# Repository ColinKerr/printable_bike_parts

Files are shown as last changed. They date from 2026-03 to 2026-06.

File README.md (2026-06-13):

# Printable Bike Parts

A repo for bike parts you can 3d print

## Shimano 333 3-speed parts

Replacement parts for shimano 333 3 speed internal hub parts.

- [Top Cover](./shimano_333/TopCover.md) - Replaces often broken top cover.

## Clips

Various clips, tabs and screws used on bicycles.

- [Spoke Reflector Tab](./Clips/ReflectorSpokeTab.md) - Replaces tab used to hold reflectors on wheels via the spokes.
- [Spoke Reflector Screw](./Clips/ReflectorSpokeScrew.md) - Replaces screw used to hold reflectors on wheels via a spoke.

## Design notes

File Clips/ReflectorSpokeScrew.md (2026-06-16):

# Reflector Spoke Screw

Used on many modern bikes to hold wheel spoke reflectors onto a spoke.  The original part often breaks, or gets lost, this part is similar to the original but is modified to be printable without supports.

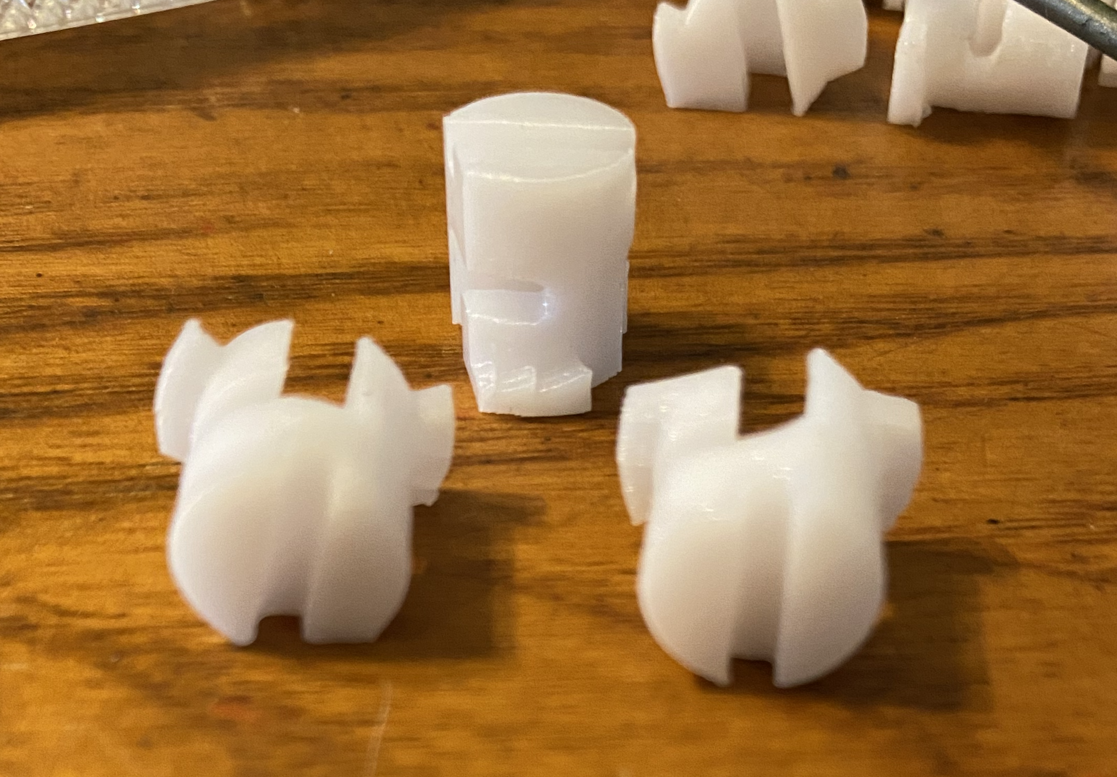
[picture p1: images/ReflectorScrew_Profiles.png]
Reflector Screw Profile


## Assembly instructions

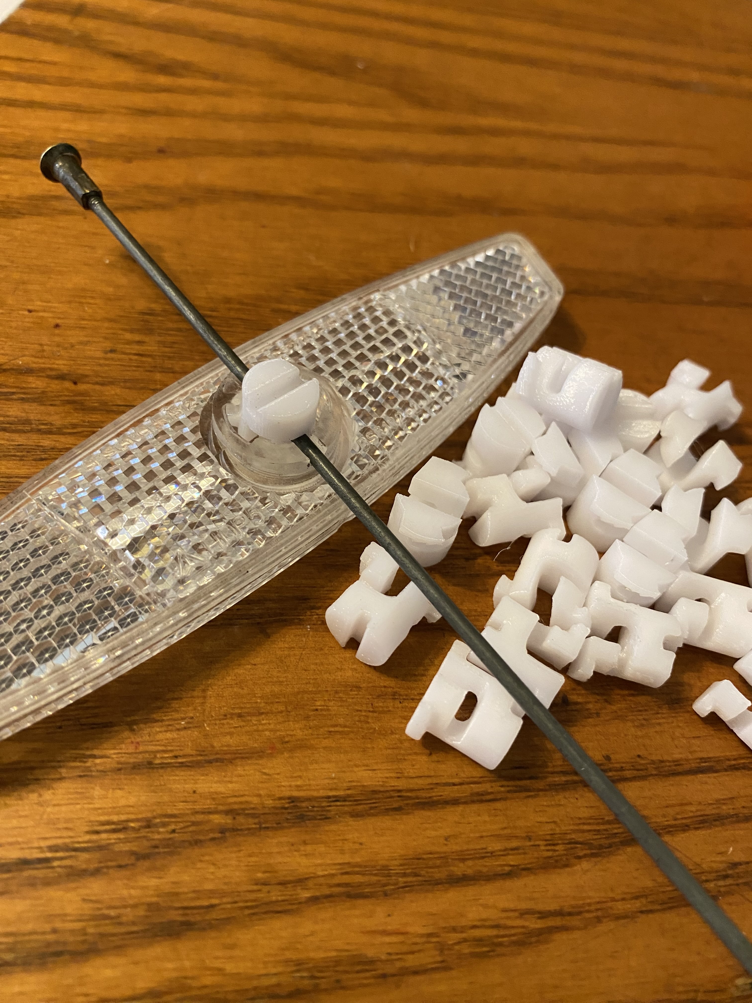
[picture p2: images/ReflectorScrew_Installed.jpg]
Reflector Screw Assembled


> Note: Make sure to press in with screw driver before turning

Use replacement screw as you would the original screw but be careful as PETG might be more flexible than original making part more prone to bend.

## Print settings

- PETG Suggested
  - PLA was to brittle for me but some other material stiffer than PETG would be ideal
- Print flat side down
- 100% infill
- 4 perimeters
- 0.1mm layer height
- No supports

> Warning: Bed adhesion is low, I suggest using smooth print bed or adhesion helper.

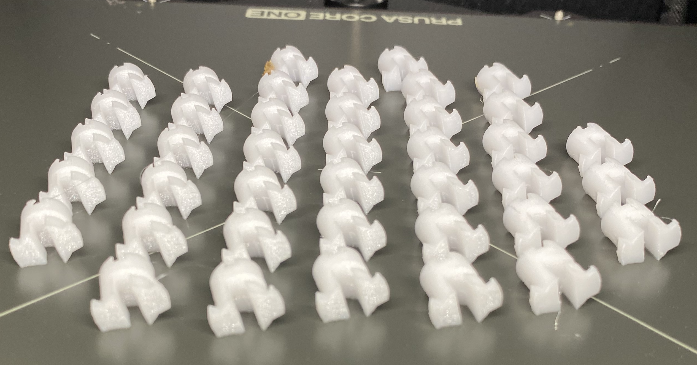
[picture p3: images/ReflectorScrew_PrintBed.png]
Reflector Screw On Print Bed


## ReflectorSpokeScrew.scad

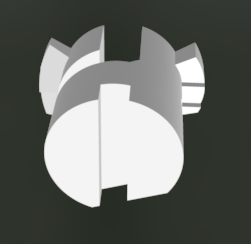
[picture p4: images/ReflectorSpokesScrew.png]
3d model of screw


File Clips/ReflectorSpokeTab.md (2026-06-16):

# Reflector Spoke Tab

Used on many older bikes to hold wheel spoke reflectors onto spokes.  The original part often breaks, this is a clone or the original part, best printed in PETG.

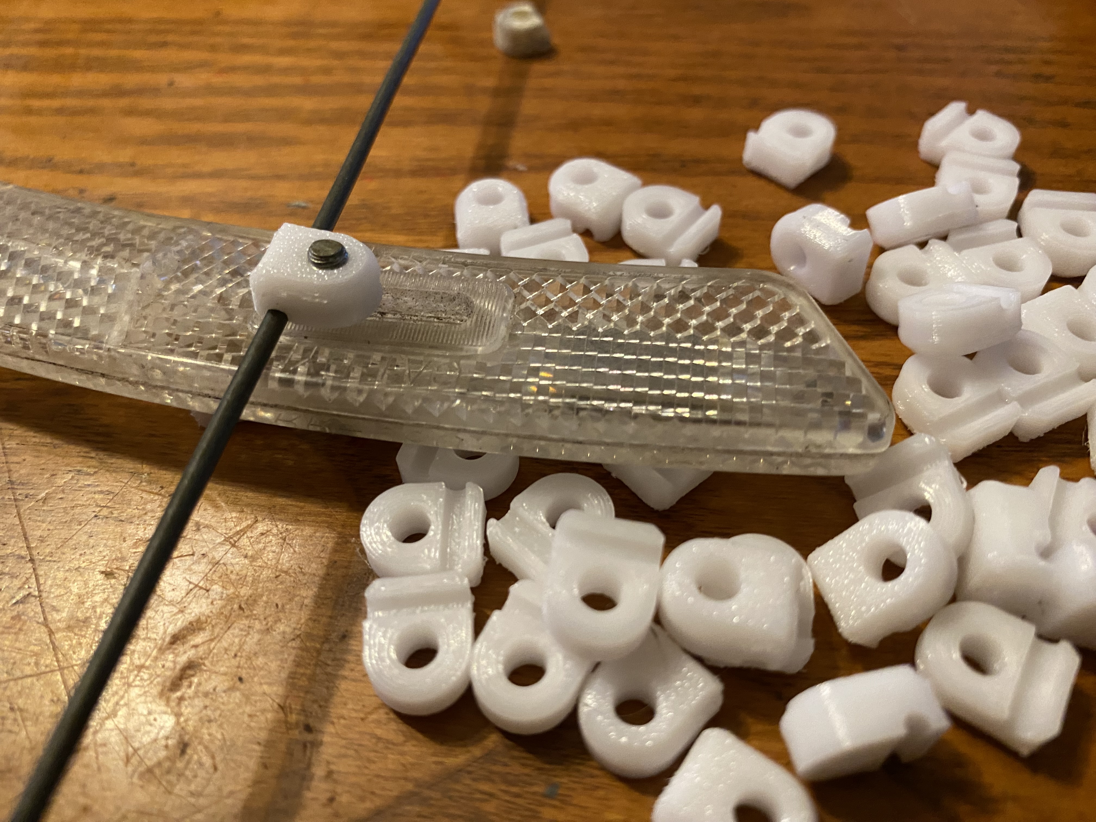
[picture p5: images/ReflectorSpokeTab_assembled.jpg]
Spoke Tabs


## Assembly instructions

> Note: Make sure grove in tab fits snugly around spoke be for assembly

Use replacement tab as you would the original tab but note that screw will thread into plastic on first use.

## Print settings

- PETG Suggested
- Print top side down
- 100% infill
- 4 perimeters
- 0.1mm layer height
- No Supports

## ReflectorSpokeTab.scad

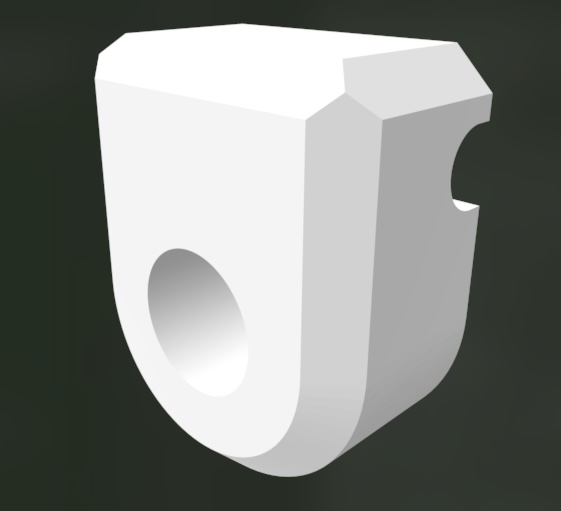
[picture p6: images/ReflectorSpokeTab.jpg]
3d model of tab


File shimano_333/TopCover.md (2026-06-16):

# Top Cover

The plastic top cover on the shifter is easily broken rendering the shifter non-functional.  The rest of the shifter generally remains functional, so a replacement top cover fixes the issue.

This part is designed to use either 4mm housing with a plastic cable end or a 5 mm housing with a metal end.  Reuse the screw, ball bearing and internal metal plate from the original shifter.

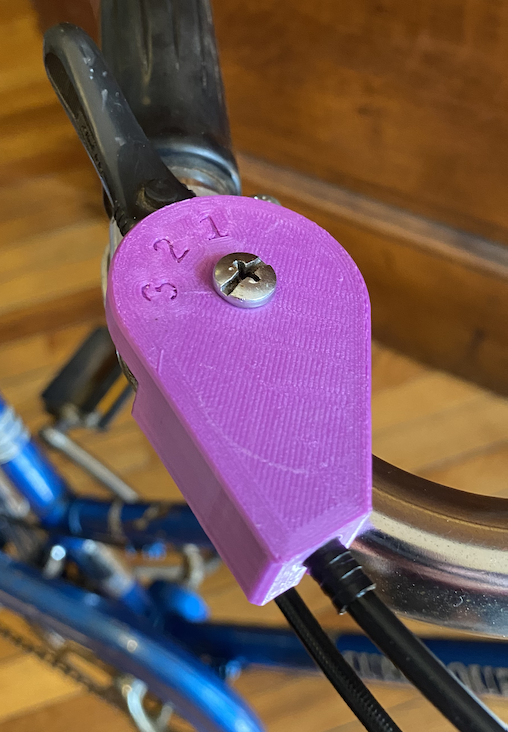
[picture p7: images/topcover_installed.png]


## Assembly instructions

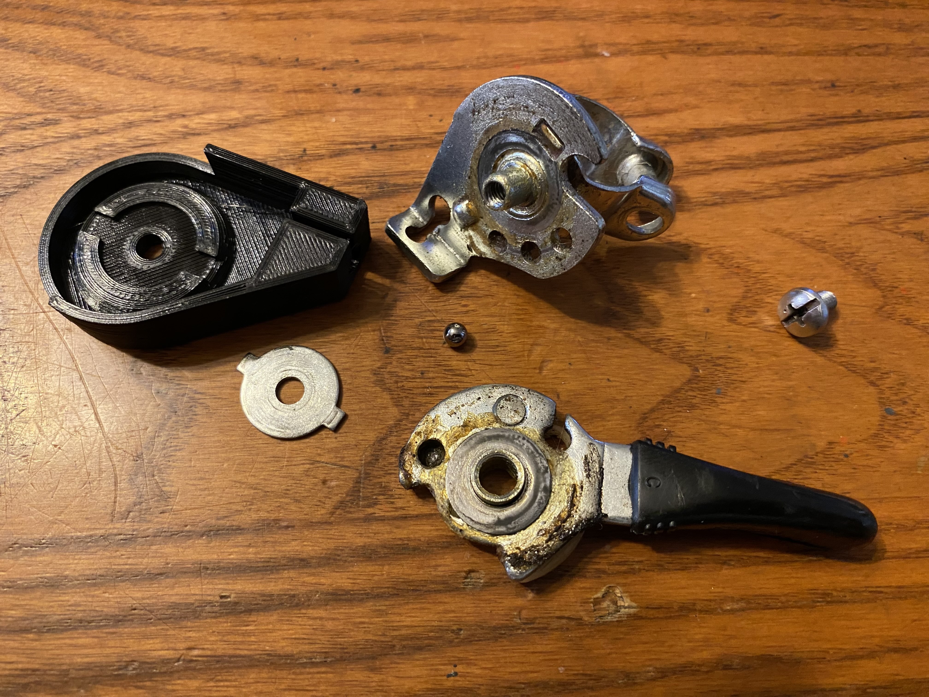
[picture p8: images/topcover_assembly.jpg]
shifter dissassembled


Dissassemble the broken shifter keeping mind of the order of parts.  Swap the broken housing for the 3d printed one and reassemble.  Mind the ball bearing, it may be loose or missing.

> Note 1: Some models of this shifter have tabs on the top metal washer some do not, both models work with the new top cover.
> Note 2: Ball bearing is 3/16"
> Note 3: Apply grease to the moving assemblies if dry

## Print settings

- PETG suggested
- Print top side down
- 100% infill
- 4-6 perimeters
- 0.1mm layer height
- (Optional) Fuzzzy skin on outside walls and chamfers to hide print lines

## TopCover.scad

This design has more plastic surrounding the cable housing area than the original for increased strength.

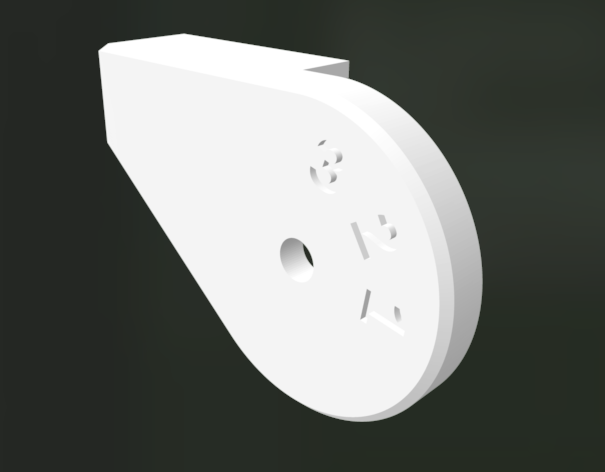
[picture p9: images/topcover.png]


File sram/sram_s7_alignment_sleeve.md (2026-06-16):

# SRAM S7 Alignment Sleeve

I didn't design this part so I will just link to post and describe how best to print it.  The part could be improved to have a longer tab so it is easier to remove from the click box but I did not attempt.

The STL can be found on [Thingiverse](https://www.thingiverse.com/thing:4240412)

## Print Settings

- PETG Suggested
- Print tab side down
- 100% infill
- 4 perimeters
- 0.1mm layer height
- Supports to Bed Only

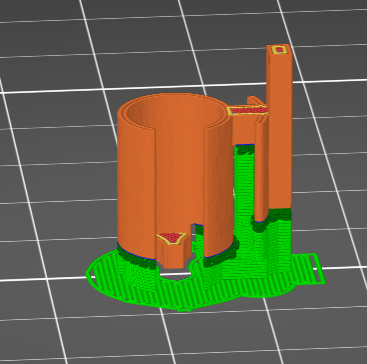
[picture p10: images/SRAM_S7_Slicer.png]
Sleeve in Slicer


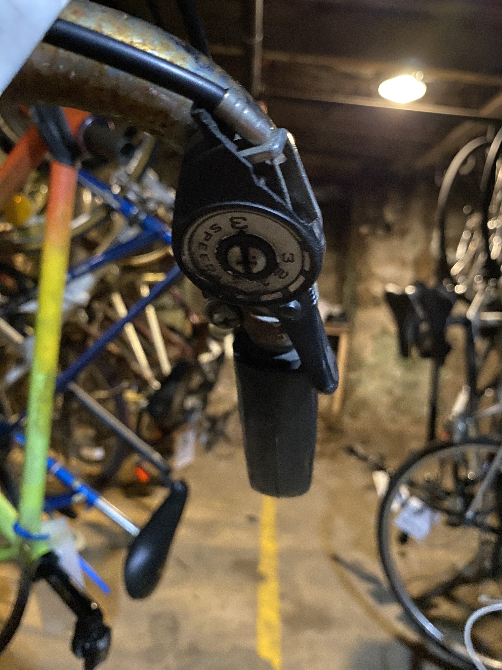
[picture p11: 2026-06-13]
images/topcover_broken.jpg

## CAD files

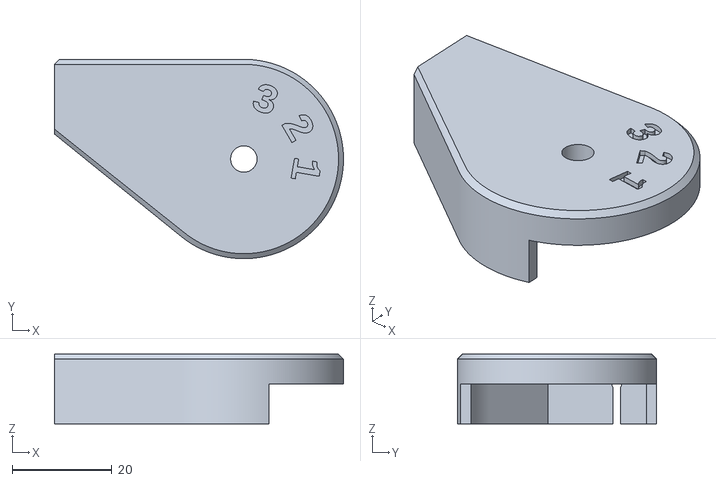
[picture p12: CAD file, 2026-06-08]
shimano_333/TopCover.stl
58.0 x 40.0 x 14.0

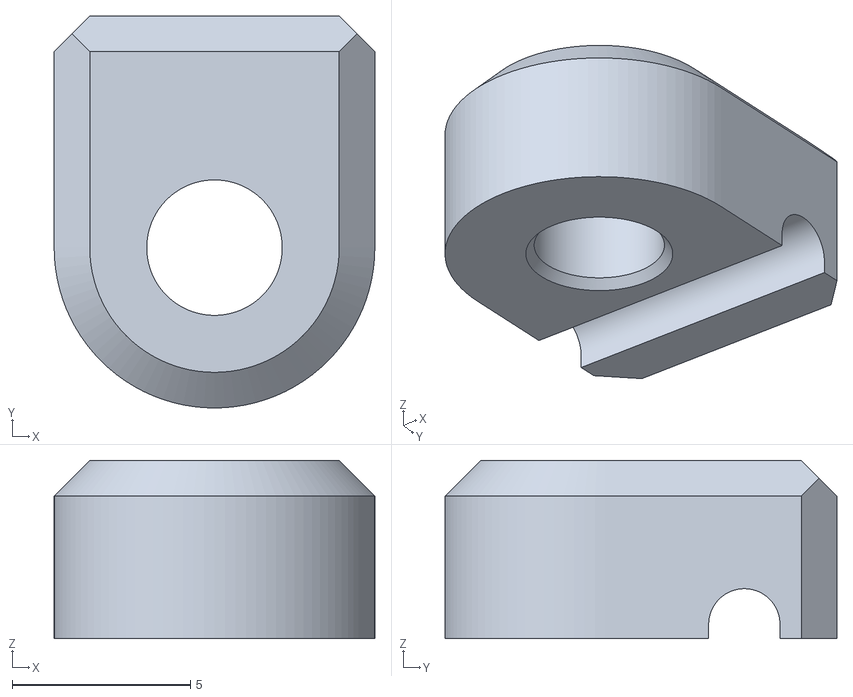
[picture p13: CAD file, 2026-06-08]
Clips/ReflectorSpokeTab.stl
9.00 x 11.0 x 5.00

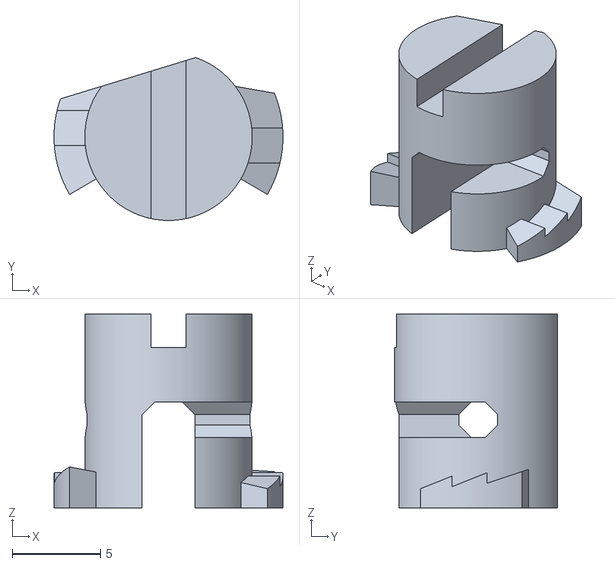
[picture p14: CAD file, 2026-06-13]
Clips/ReflectorSpokeScrew.stl
13.0 x 9.25 x 11.0

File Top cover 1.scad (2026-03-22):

$fn = 64;

module circle_text(text, size, height, radius, start_angle, char_spacing) {
    length = len(text);
    for(a=[0:length]) {
        rotate([0, 0, length / (2 * 10) - (a * char_spacing) + start_angle])
        translate([2 * radius, 0, 0])
        linear_extrude(height)
        rotate([0, 0, -90])
        text(text[a], size, font = "Liberation Mono:style=Bold", halign = "center", valign = "bottom", spacing = 1, direction = "ltr", $fn = 100);
    }
}

module create_shell (includeTab, roundEdges) {
    union() {
        hull () {
            cylinder(14, 20, 20, center = true);
            translate([-14, 9, 0]) {
                cube([28, 22, 14], center = true);
            }
        }
        if (includeTab) {
            translate([-33, 12.5, 0]) {
                cube([10, 15, 14], center = true);
            }
        }
    }
}

module create_inner_support () {
    difference () {
        translate ([0, 0, 2]) {
            difference () {
                cylinder(3.5, 13.5, 16);
                translate ([0, 0, .5]) {
                    cylinder(1.4, 9.3, 9.3, center = true);
                    cube([30, 4.8, 1.4], center = true);
                }
            }
        }

    }
}

module create_skirt_cutout () {
    translate([-5, 0, -9]) {
        cube([30, 30, 10]);
    }
    translate([5, -20, -9]) {
        cube([30, 30, 10]);
    }
}

module create_cable_hole () {
    translate ([-27, 12, 2]) {
        rotate([0, -90, 0]) {
            cylinder(30, 2.95, 2.95);
            translate([0, 0, -3]){
                cylinder(50, 1, 1);
            }
            translate([-11, -0.75, -3]){
                cube([11, 1.5, 30]);
            }
        }
    }
}

module create_text () {
    translate([0, 0, 6.1]) {
        circle_text("321", 5, 1, 5, 70, 40);
    }
}

difference () {
    union () {
        difference () {
            create_shell(true, true);
            translate ([0, 0, -1.5]) {
                scale ([0.9, 0.9, 1]) {
                    create_shell(false, false);
                }
            }
        }
        create_inner_support();
    }
    // Create screw hole
    cylinder(30, 2.65, 2.65, center = true);
    
    create_skirt_cutout();
    create_cable_hole ();
    create_text();
}

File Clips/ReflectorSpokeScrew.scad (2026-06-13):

include <Chamfers-for-OpenSCAD/Chamfer.scad>;

$fn = 256;

difference() {
    union() {
        cylinder(h=11, d=9.5);
        difference() {
            cylinder(h=3, d=13);
            cut_wedge();
            translate([3,-2.5,1])
                rotate([90,0,90])
                    ridges();
            translate([-3,2.5,1])
                rotate([90,0,270])
                    ridges();
        }

    }
    translate([-1.5,-7,-0.1]) // main vertical cut
        chamferCube([3,14,6.1], chamfers = [[0,0,0,0],[0,1,1,0],[0,0,0,0]], ch = 0.7);
    translate([-1,-5,9.1]) // top screwdriver cut
        cube([2,10,2]);
    translate([0,-8.9,4])
        chamferCube([10, 10, 2], chamfers = [[0,1,1,0],[0,0,0,0],[0,0,0,0]], ch = 0.7);
    translate([-10,-1.1,4])
        chamferCube([10, 10, 2], chamfers = [[1,0,0,1],[0,0,0,0],[0,0,0,0]], ch = 0.7);
    rotate([0,0,17])
        translate([-7, 3.85, -1]) // Flat side
            cube([14,2,14]);
}

//cut_wedge();


module wedge() {
    translate([0,0,-0.1]){
        linear_extrude(height = 3.2) {
            polygon([[0,0],[12,7],[12,10],[-12,10],[-12,7]]);
        }
        linear_extrude(height = 3.2) {
            polygon([[0,0],[-12,-7],[-12,-10],[12,-10],[12,-7]]);
        }
    }
}

module cut_wedge() {
    translate([0,0,-0.05]){
        linear_extrude(height = 3.2) {
            polygon([[0,0],[3,3],[7,2.3],[12,7],[12,10],[-12,10],[-12,7],[-7,2.3],[-3,3]]);
        }
        linear_extrude(height = 3.2) {
            polygon([[0,0],[-12,-7],[-12,-10],[12,-10],[12,-7]]);
        }
    }
}

module ridges() {
    linear_extrude(height= 5) {
        polygon([[-1,0],[1,0.8],[1,0.2],
                 [3,1],[3,0.4],[6,1.4],
                 [6,4],[-1,6],[-1,0.7]]);
    }
}

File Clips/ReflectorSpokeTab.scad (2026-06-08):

include <Chamfers-for-OpenSCAD/Chamfer.scad>;

$fn = 256;

chamfer = 1;

difference() {
    hull(){
        chamferCylinder(5, 4.5, 4.5, 0, chamfer);
        translate([-4.5,0,0]){
            chamferCube([9,6.5,5], chamfers = [[0,0,1,0],[0,1,1,0],[0,0,1,1]], ch = chamfer);
        }
    }
    translate([0,0,-0.5]) cylinder(h=6, d=3.8);
    translate([0,0,-0.01])cylinder(h=0.3, d1=4.3, d2=3.8);
    rotate([90,0,90]) 
        translate([3.9,0.4,-5]) {
            cylinder(h=10, d=2);
            translate([-1,-2,0])
                cube([2,2,10]);
            }
}

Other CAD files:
shimano_333/TopCover.scad

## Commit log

2026-03-22 add versions 1 and 2 of the Shimano 333 3-speed top cover
    [Top cover 1.scad, Top cover 1.stl, Top cover 2.scad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]
2026-06-08 Reorganize repo, update top cover to new mod and remove v1, add reflector spoke tab
    [ReflectorSpokeTab.scad, ReflectorSpokeTab.stl, Top cover 1.stl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]
2026-06-13 Add Reflector Spoke Screw first draft and update Reflector Spoke Tab page
    [ReflectorSpokeScrew.scad, ReflectorSpokeScrew.stl]
